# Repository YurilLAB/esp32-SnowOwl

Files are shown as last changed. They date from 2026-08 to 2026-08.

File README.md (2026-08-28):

<div align="center">

# 🦉 ESP32-SnowOwl

**A multi-purpose wireless _offensive &amp; defensive_ security multitool.**

Three processors — **ESP32-S3 + ESP32-C5 (5 GHz Wi‑Fi) + ARM Linux** — driving a wall of radios and readers: dual‑band Wi‑Fi, BLE, 2.4 GHz, Sub‑GHz, **LoRa**, IR, **NFC**, **125 kHz RFID**, **iButton** &amp; GPS, in one stackable handheld.








</div>

> ⚠️ **Authorized use only.** SnowOwl is built for security research, education, CTFs, and testing on systems you own or are explicitly authorized to assess. You are solely responsible for complying with all applicable laws and regulations.

---

## 📖 About

**ESP32-SnowOwl** is a hardware evolution of [CiferTech's **ESP32‑DIV**](https://github.com/cifertech/ESP32-DIV) — the open-source ESP32‑S3 wireless multitool. SnowOwl keeps the entire ESP32‑DIV toolset and then piles on the compute, radios and readers the stock board doesn't have.

**Three processors, each doing what it's best at:**

- 🦅 **ESP32‑S3 — the controller.** The base ESP32‑DIV brain: the on‑device UI, 2.4 GHz Wi‑Fi &amp; BLE, and orchestration of every radio.
- 📡 **ESP32‑C5 — the 5 GHz reach.** A dual‑band **Wi‑Fi 6 (2.4 + 5 GHz)** co‑processor that adds the entire **5 GHz** band the S3 can't touch, on its own antenna and its own regulated rail.
- 🐧 **RV1106 ARM Linux — the analyst.** A real Linux computer (Luckfox Core1106) for capture, monitoring, scripting and heavy on‑device tooling — self‑powered from **its own USB‑C**.

Offense on the talons, analysis in the eyes. Silent, patient, built for the dark — the snow owl fits.

---

## 🦉 What SnowOwl adds over ESP32‑DIV

| Addition | Part | What it brings |
|---|---|---|
| 📡 **5 GHz Wi‑Fi co‑processor** | ESP32‑C5‑WROOM‑1U | Dual‑band **Wi‑Fi 6 (2.4 + 5 GHz)** — the 5 GHz band the ESP32‑S3 can't reach. Own U.FL antenna, own AP7361C LDO rail, UART‑linked to the S3. |
| 🐧 **ARM Linux co‑processor** | Luckfox RV1106 (Core1106) | A genuine Linux computer on the shield for capture, monitoring and heavy tooling. Self‑powered from **its own USB‑C**. |
| 🧲 **NFC** (13.56 MHz) | PN532 | Read / emulate / relay over a **dedicated I²C bus** owned by the S3 — independent of the radios. |
| 📇 **125 kHz LF RFID** | HTRC110 + coil | Low‑frequency prox‑card read &amp; emulation (EM4100‑class) — a band the stock board lacks. |
| 🔑 **iButton / 1‑Wire** | 1‑Wire header | Dallas iButton + 1‑Wire contact interface. |
| 📻 **LoRa / long‑range Sub‑GHz** | SX1262 (+ Johanson match) | Long‑range LoRa &amp; FSK on Sub‑GHz, alongside the OOK/ASK radios. |
| 📻 **High‑performance Sub‑GHz** | CC1200 | A higher‑performance Sub‑GHz transceiver in addition to the classic CC1101. |
| 💾 **External flash** | W25Q128 (16 MB) | Non‑volatile storage for captures, logs and dumps. |
| 🧱 **4‑layer, power‑hardened PCB** | — | Dedicated **GND** and **3V3** planes, per‑rail decoupling and bulk caps for clean RF and stable multi‑radio operation. |

---

## 🎯 Features

SnowOwl runs the full **ESP32‑DIV** firmware feature set on the ESP32‑S3, extended with the SnowOwl radios and readers. Capabilities by band:

### 📡 Wi‑Fi — 2.4 GHz (ESP32‑S3) **+ 5 GHz (ESP32‑C5)** · **5 GHz is NEW**
| Capability | Notes |
|---|---|
| Dual‑band recon &amp; scanning | AP / station discovery across **2.4 *and* 5 GHz**, channels, RSSI |
| Deauth / attack testing | Targeted &amp; broadcast frame testing, now on 5 GHz networks too |
| Beacon / probe flooding | SSID beacon spam, probe generation |
| Packet monitor / capture | Sniffing, with hand‑off to the ARM side for storage &amp; analysis |
| Evil‑portal / captive testing | Rogue‑AP and captive‑portal workflows |

### 🔵 Bluetooth / BLE
| Capability | Notes |
|---|---|
| BLE scan &amp; recon | Device discovery, service enumeration |
| Advertising / spam | BLE advertisement flooding &amp; spoofing |
| Proximity‑pairing tests | Device‑spam nuisance testing |

### 📶 2.4 GHz / nRF24 (3× nRF24L01+)
| Capability | Notes |
|---|---|
| Channel scanner / analyzer | 2.4 GHz spectrum sweep across three radios |
| Multi‑channel jamming (test) | Wide/targeted 2.4 GHz interference testing |

### 📻 Sub‑GHz — CC1101 · CC1200 · **SX1262 LoRa**
| Capability | Notes |
|---|---|
| Scan &amp; frequency analysis | RSSI sweep, signal hunting |
| Capture / replay | Record &amp; re‑transmit OOK/ASK signals |
| **LoRa / long‑range** | SX1262 for LoRa &amp; long‑range FSK |
| Jamming (test) | Sub‑GHz interference testing |

### 📺 Infrared (TSOP1838 RX + IR TX)
| Capability | Notes |
|---|---|
| Receive / decode | Capture IR remotes |
| Send / replay | Transmit stored or brute‑forced codes |

### 🧲 NFC / RFID — 13.56 MHz (PN532)
| Capability | Notes |
|---|---|
| Read / dump | MIFARE‑class tags &amp; UIDs |
| Emulate / relay | Card emulation and relay over the dedicated I²C bus |

### 📇 LF RFID — 125 kHz (HTRC110) &amp; 🔑 iButton · **NEW**
| Capability | Notes |
|---|---|
| 125 kHz read / emulate | EM4100‑class prox cards |
| iButton / 1‑Wire | Dallas contact keys |

### 🛰️ GPS (NEO‑M9N)
| Capability | Notes |
|---|---|
| Location &amp; time | Fix, NMEA, wardriving support |

### 🐧 ARM Linux co‑processor (RV1106) · **NEW**
| Capability | Notes |
|---|---|
| On‑device capture &amp; storage | Long‑running packet/loot capture without a laptop, to the 16 MB flash / SD |
| Monitoring / blue‑team | Run standard Linux security &amp; monitoring tooling on‑device |
| Scripting &amp; automation | Python/shell orchestration of the S3 &amp; C5 radios |

### 🧰 Device &amp; System
| Capability | Notes |
|---|---|
| Display UI | On‑device menu on the ESP32‑DIV TFT |
| Storage | microSD + **16 MB external flash** |
| Settings | Per‑module configuration |

> The exact per‑tool menu is inherited from the ESP32‑DIV firmware — see the [ESP32‑DIV wiki](https://github.com/cifertech/ESP32-DIV/wiki) for the full tool list.

---

## 🔧 Hardware Overview

### 🧠 Compute
- **ESP32‑S3** — application processor, 2.4 GHz Wi‑Fi &amp; BLE, UI (on the main board)
- **ESP32‑C5‑WROOM‑1U** — dual‑band **2.4 / 5 GHz Wi‑Fi 6** co‑processor (U.FL antenna, AP7361C LDO rail, UART link)
- **Luckfox RV1106 (Core1106)** — ARM Linux SoM, self‑powered via its **own USB‑C**

### 📡 Radios
- **3× nRF24L01+** — 2.4 GHz
- **CC1101** + **CC1200** — Sub‑GHz transceivers
- **SX1262** (+ Johanson integrated match) — LoRa / long‑range Sub‑GHz
- **7× SMA** antenna ports + U.FL

### 🧲 Readers &amp; sensors
- **PN532** — 13.56 MHz NFC (dedicated I²C bus, 27.12 MHz)
- **HTRC110** + coil — 125 kHz LF RFID
- **iButton / 1‑Wire** contact interface
- **TSOP1838** IR receiver + IR transmit
- **NEO‑M9N** — GPS

### 🔌 Power, storage &amp; protection
- **W25Q128** — 16 MB SPI flash
- microSD
- **AP7361C‑3.3** LDO (C5 rail), dedicated USB‑C for the ARM SoM
- **USBLC6‑2SC6** USB ESD protection, **SN74LVC2G34** level buffer
- Power hardening: bulk + per‑rail decoupling capacitors

Mates to the main board through the existing 20‑pin stack header; pogo/standoff holes are kept clear for a flat stack.

---

## 🧱 PCB / Manufacturing

- Designed in **KiCad 10**.
- **4‑layer stackup** — `F.Cu (signal) · In1 (GND plane) · In2 (3V3 plane) · B.Cu (signal)` for clean RF return paths and a quiet supply.
- Power‑planned per the datasheets of each part (per‑rail decoupling + bulk); RF nets use integrated matching where the transceiver vendors provide it.
- Intended for standard 4‑layer fabrication (e.g. JLCPCB); the 4‑layer option adds only a few dollars per unit over 2‑layer.

> **Status:** hardware design in active development. Placement and power are complete; signal routing is being finished. Renders and design notes live in [`/hardware`](hardware).

---

## ⚠️ Legal &amp; Responsible Use

SnowOwl is an **offensive *and* defensive** research platform. It is intended **only** for:

- testing systems you **own** or are **explicitly authorized** to assess,
- security education, CTFs, and lab research,
- defensive monitoring and blue‑team work.

Do **not** use it to access, disrupt, or interfere with networks, devices, cards, or systems you do not own or lack permission to test. Radio transmission is regulated — respect your local RF laws and licensed bands. **You** are responsible for how you use this tool.

---

## 📜 License

Released under the **MIT License** — see [`LICENSE`](LICENSE).

SnowOwl is a derivative of **ESP32‑DIV** (© CiferTech, MIT). The original work's terms are honored and its authors are credited below.

---

## 🙌 Credits

- **[CiferTech](https://github.com/cifertech)** — the original [ESP32‑DIV](https://github.com/cifertech/ESP32-DIV) platform and firmware that SnowOwl builds on. 🙏
- **YurilLAB** — SnowOwl hardware: the 5 GHz Wi‑Fi + ARM‑Linux compute, the NFC / 125 kHz RFID / iButton / LoRa additions, power hardening, and the 4‑layer redesign.

---

## 💬 Contributing &amp; Support

Issues, ideas, and pull requests are welcome. If SnowOwl is useful to you, a ⭐ helps.

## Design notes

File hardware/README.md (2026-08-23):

# 🦉 ESP32-SnowOwl — Hardware

KiCad design for the SnowOwl 2-board stack (main board + shield).

## PCB source → [`../PCB/`](../PCB)

All CAD lives under [`../PCB/`](../PCB), with old and new kept separate:

- **[`PCB/v2-compact/`](../PCB/v2-compact)** — the **active** ground-up remake: a compact,
  deliberately floorplanned **2-board stack** (`main-board/` + `shield/`). Start with
  [`PCB/v2-compact/PLACEMENT.md`](../PCB/v2-compact/PLACEMENT.md) for the zone map and the
  bus/routing strategy.
- **[`PCB/v1-original/`](../PCB/v1-original)** — the original board, archived (renders only).

## Renders (v1)

| Front | Back |
|---|---|
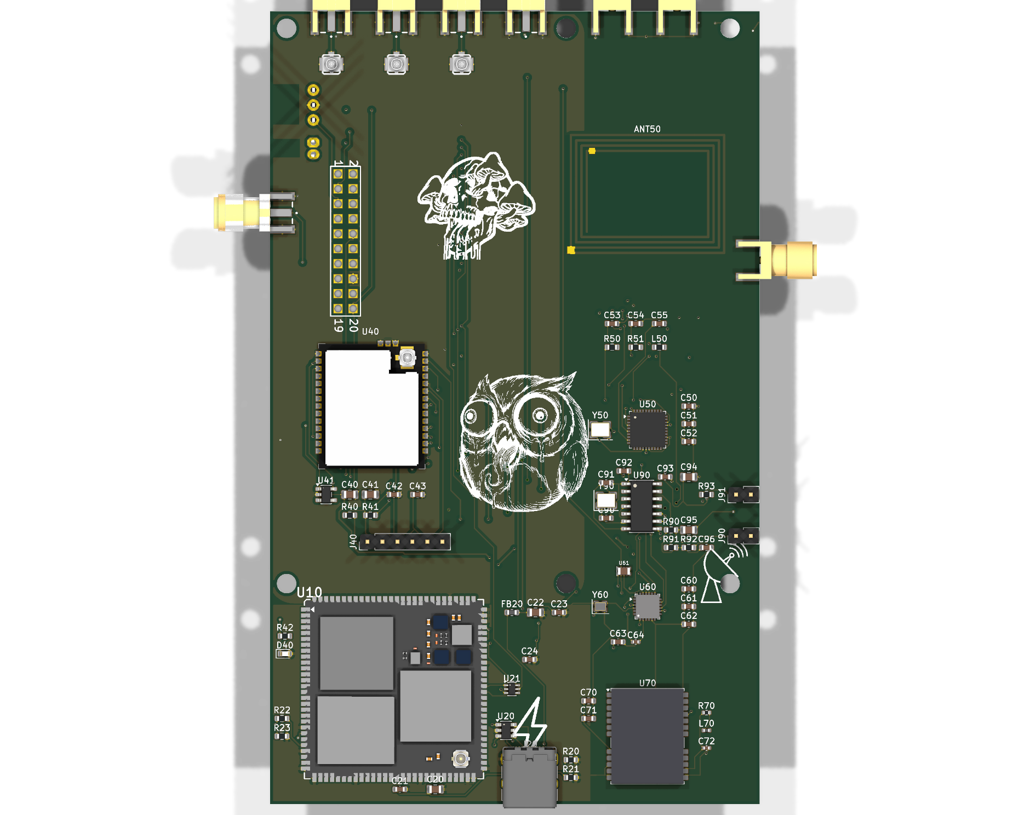
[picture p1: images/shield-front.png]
front
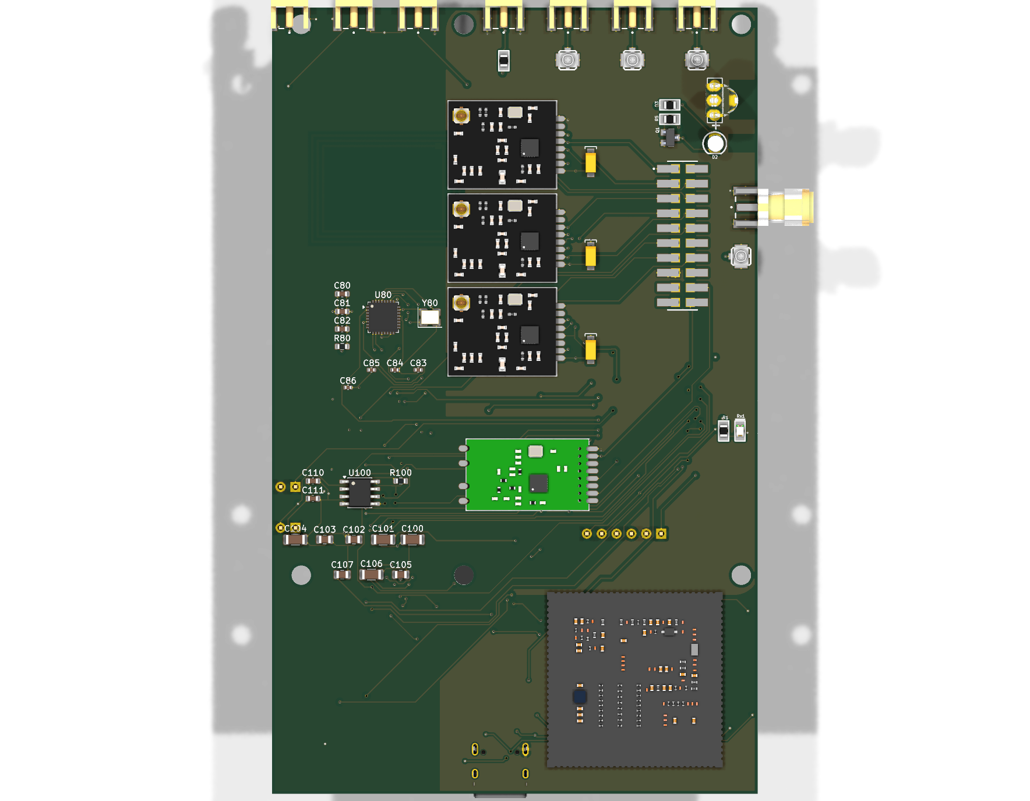
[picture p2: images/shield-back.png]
back
|  |  |

## Shield highlights

- **ESP32-C5-WROOM-1U** — dual-band **2.4 / 5 GHz Wi-Fi 6** co-processor (adds the 5 GHz band the S3 lacks); own U.FL antenna + **AP7361C-3.3** LDO rail, UART-linked to the S3.
- **Luckfox RV1106 (Core1106)** ARM Linux SoM — self-powered from its **own USB-C** (isolated from the main board's supply).
- **PN532 NFC** (13.56 MHz, 27.12 MHz clock) on a dedicated I²C bus owned by the ESP32-S3.
- **HTRC110 125 kHz LF RFID** front-end + coil connector.
- **iButton / 1-Wire** contact interface.
- **SX1262 LoRa** (+ Johanson integrated match) and **CC1200** high-performance Sub-GHz, alongside the classic CC1101.
- **3× nRF24L01+** (2.4 GHz) and **NEO-M9N** GPS.
- **W25Q128** 16 MB external flash for captures/logs.
- Power hardening: bulk + per-rail decoupling capacitors; **USBLC6** USB ESD protection.
- Mates to the main board via the existing 20-pin stack header; pogo/standoff holes kept clear for a flat stack.

## Stackup (4-layer)

| Layer | Role |
|---|---|
| `F.Cu`  | Signal |
| `In1.Cu` | **GND plane** |
| `In2.Cu` | **3V3 plane** |
| `B.Cu`  | Signal |

Dedicated planes give every radio a solid return path and a quiet supply — the single biggest win for multi-radio RF behaviour. Standard 4-layer fabrication (e.g. JLCPCB) adds only a few dollars per unit over 2-layer.

## Status

**Redesign in progress — v2 (2-board stack).** The board is being remade from scratch to
fix v1's spread-out placement (which forced long cross-board traces). v2 keeps every
radio/reader but floorplans each subsystem deliberately so routing stays local.

Current v2 state (in [`../PCB/v2-compact/`](../PCB/v2-compact)): floorplan **skeleton** —
both KiCad projects open with the compact `60 × 85 mm` outline, the 4-layer stackup, the
shared 20-pin `J1` stack datum, mounting holes, and labelled placement zones. Symbols,
footprints and routing are the next passes. The RF nets (Sub-GHz, NFC coil, GPS) are still
reserved for short, matched hand-routing.

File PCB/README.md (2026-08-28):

# 🦉 SnowOwl — PCB

**Clean slate.** All previous CAD — boards, schematics, footprints, floorplan and renders — has
been wiped. The hardware direction is changing and the design is being started over from scratch.

```
PCB/
└── RESEARCH.md    ← component & schematic reference carried over from the old attempt
```

## RESEARCH.md

The only thing kept: the electrical research worth not repeating.

- **System architecture** — which processor owns what, and the SPI-spine approach.
- **Component inventory** — every radio/reader, and which ones are self-contained modules vs.
  chip-down parts that need a crystal and an RF front-end.
- **Power** — the single-USB-C / battery topology, plus **datasheet pinout corrections** for the
  charger, regulators and fuel gauge (the old symbols had invented pinouts).
- **RF front-end topologies** — matching + filter chains for the chip-down radios, with the
  caveat that every L/C value still needs VNA tuning.
- **Schematic gotchas** — including the net-merge bug that silently shorted whole nets twice.

It deliberately assumes **no particular board size, layout or form factor**, so none of it
constrains the new design.

> Fabrication outputs (`gerbers-out/`, zips) are git-ignored.

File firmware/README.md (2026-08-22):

# 🦉 ESP32-SnowOwl — Firmware

SnowOwl is a **three-processor** device, so there are three firmware sides.

## 🦅 ESP32-S3 (controller + main radios)

- **Base:** the [ESP32-DIV firmware](https://github.com/cifertech/ESP32-DIV) (Arduino / PlatformIO) — the full wireless toolset runs unchanged.
- **SnowOwl add-ons:**
  - **PN532 NFC** over the dedicated I²C bus.
  - **HTRC110 125 kHz LF RFID** read / emulate.
  - **iButton / 1-Wire** contact interface.
  - **SX1262 LoRa** + **CC1200** Sub-GHz drivers.

Flashing follows the ESP32-DIV instructions (USB-C, `esptool` / PlatformIO, or the browser flasher).

## 📡 ESP32-C5 (5 GHz Wi-Fi co-processor)

- Runs its own ESP-IDF firmware and is **UART-linked to the S3**, which requests 5 GHz scans/attacks and receives results to draw on the TFT.
- Adds the dual-band **2.4 / 5 GHz Wi-Fi 6** capability the S3 (2.4 GHz only) can't provide.
- Flashed over its own USB / `C5_PROG_UART` header.

## 🐧 RV1106 (ARM Linux co-processor)

- Runs a standard Linux userland (Luckfox Buildroot / Ubuntu image) from its own storage, powered by its own USB-C.
- Talks to the ESP32-S3 over the inter-processor link for capture, monitoring and orchestration.
- Intended home for heavier tooling the ESP32 can't run — packet capture, analysis, scripting, blue-team monitoring.

## Status

Firmware integration is in progress. Until the SnowOwl builds are published here, use the upstream [ESP32-DIV firmware + wiki](https://github.com/cifertech/ESP32-DIV/wiki) as the reference for the base toolset.

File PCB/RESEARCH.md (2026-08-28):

# SnowOwl / ESP32-BlackRaven — component & schematic research

Electrical reference carried over from the earlier attempt. **All CAD (boards, schematics,
floorplan, renders) was wiped and is being redone** — the project direction is changing. What
survives here is only the research worth not repeating: what the parts are, how they connect,
and the datasheet findings.

Nothing here assumes a particular board size, layout or form factor.

---

## 1. System architecture

| Controller | Owns | Link |
|---|---|---|
| **ESP32-S3** | UI: TFT, LEDs, nav buttons, microSD; and NFC, iButton, IR | the brain |
| **ESP32-C5** | the SPI radio spine — CC1101, CC1200, SX1262, 3× nRF24, W25Q128 flash; plus 5GHz Wi-Fi and the 125kHz HTRC110 | UART pair + data-ready line to the S3 |
| **RV1106** | ARM Linux SoM, own microSD | UART to the S3 |

**Key decision:** the C5 sits among the radios and masters one short SPI spine; every radio taps
it with a short stub. The S3 never reaches the radios directly — it commands the C5 over UART.
An **MCP23S17** expander generates the per-radio chip-selects so the C5 doesn't burn GPIO.

## 2. Component inventory

| Function | Part | Notes |
|---|---|---|
| Main MCU | ESP32-S3 | UI + brain |
| Radio co-processor | ESP32-C5-WROOM-1U | 5GHz Wi-Fi; **module — own antenna** |
| CS expander | MCP23S17 | SPI → chip-selects |
| Sub-GHz | **CC1101** | **plug-in module** (2×4 header) |
| Sub-GHz | **CC1200** | chip-down, needs 40MHz xtal + RF front-end |
| LoRa | **SX1262** | chip-down, needs 32MHz xtal + RF front-end |
| 2.4GHz | 3× nRF24L01+ | **modules — own antennas** |
| NFC | PN532 | 13.56MHz |
| LF RFID | HTRC110 | 125kHz, **5V part**, open-drain DOUT pulled to 3V3 — level-shift care needed vs the 3.3V C5 |
| GPS | u-blox NEO-M9N | chip-down, needs antenna bias-tee |
| IR | receiver + TX LED + transistor | |
| iButton | 1-Wire | |
| Flash | W25Q128 | 16MB, on the SPI spine |
| Linux | RV1106 "Core1106" SoM | + own microSD |
| Display | TFT on FPC header | |

### Radios that need on-board RF vs. those that don't
- **Need a front-end (chip-down):** CC1200, SX1262, GPS NEO-M9N.
- **Self-contained (own crystal + antenna):** nRF24 ×3, CC1101, ESP32-C5-WROOM-1U.

> **CC1101 is a module, not a chip** — a 2×4 pin header: GND, +3V3, SPI SCK/MOSI/MISO, CSN,
> GDO0, GDO2. It needs no crystal and no RF path, only decoupling. (This confused us once.)

## 3. Power

**One USB-C for the whole device.** Everything runs off the battery; USB only charges.

```
USB-C → VBUS → BQ25896 charger ─┬→ VBAT  (LiPo ~2500mAh, ≈1–2h active runtime)
                                 └→ VSYS ─┬→ TPS63020 buck-boost → +3V3
                                          └→ TPS61230A boost     → +5V
```
Plus **MAX17048** fuel gauge and **DW01A + FS8205A** cell protection, both readable over I²C.
The RV1106 has microSD but no USB port of its own — reached over UART.

### ⚠ Datasheet pinout corrections (researched, never applied — the old symbols were WRONG)

- **BQ25896** (QFN-24): has **no D+/D− pins** — it uses **PSEL (2)** and **PG (3)**.
  VBUS=1, STAT=4, SCL=5, SDA=6, INT=7, OTG=8, CE=9, ILIM=10, TS=11, QON=12, BAT=13/14,
  SYS=15/16, PGND=17/18+EP, SW=19/20, BTST=21, REGN=22, PMID=23, NC=24.
  App values: inductor **1µH**, R_ILIM ≈ **180Ω** for 2A, TS divider **10k/10k**,
  charge current set over I²C (2048mA).
- **TPS63020**: **14-pin VSON**, not 10-pin. Inductor **1.5µH**, FB **0.5V**,
  3.3V divider **R1=1M / R2=180k**.
- **TPS61230A**: **7-pin 2×2 VQFN** — CBST=1, EN=2, FB=3, VIN=4, SW=5, GND=6, VOUT=7.
  Inductor **1µH**, FB **1.2V**, 5V divider **R1=316k / R2=100k**.
- **MAX17048**: separate **CELL (2)** and **VDD (3)** pins.
- USB-C **5.1k CC resistors** — confirmed correct.

## 4. RF front-end designs

**All L/C values below are FIRST-PASS starting points — they must be tuned with a VNA** against
each chip's reference design and the final board's 50Ω trace impedance.

| Radio | Chain |
|---|---|
| **CC1200** | PA + LNA lumped match → 2-section harmonic LPF → antenna |
| **SX1262** | DC-DC coil (≈15µH) + PA-regulator cap; RFO/RFI match → 2-section LPF → antenna |
| **GPS** | active-antenna bias-tee: series DC-block cap + DC feed inductor/ferrite from the RF supply |

Edge-mount SMA convention: **pin 1 = signal, pin 2 = GND shield**, barrel pointing off the edge.

⚠ **The CC1200 RF pinout (PA / TRXSW / LNA_P / LNA_N / LPF0 / LPF1) was never datasheet-verified.**
Confirm it before designing that match again.

## 5. Schematic gotchas worth remembering

- **eeschema has no Python API.** Schematics have to be hand-authored as S-expressions (or drawn
  by hand); `kicad-cli sch export netlist` is what drives everything downstream.
- **Auto-generated stub collisions silently merge nets.** When a generator drops a short wire stub
  + net label at each pin, packing parts into a 2-D grid can land a shunt-to-GND stub exactly on a
  signal stub — fusing whole nets with no error. It bit us twice: once shorting GND to a decoupling
  net, once merging *every* antenna net into GND. **Lay each network out as a single well-spaced
  row with distinct X positions**, and always re-verify net node counts after generating — a rail
  with a suspiciously large node count means a merge happened.
- **Verify a symbol's pin count against the datasheet before trusting it** — several power ICs
  above were placeholder symbols with invented pinouts, and it wasn't caught until much later.

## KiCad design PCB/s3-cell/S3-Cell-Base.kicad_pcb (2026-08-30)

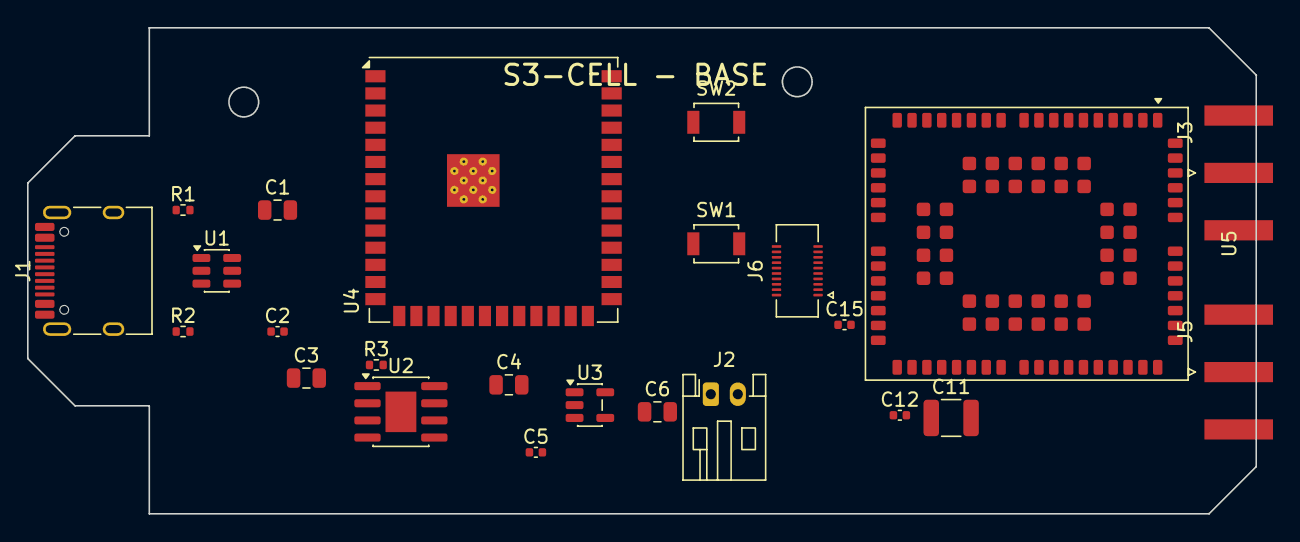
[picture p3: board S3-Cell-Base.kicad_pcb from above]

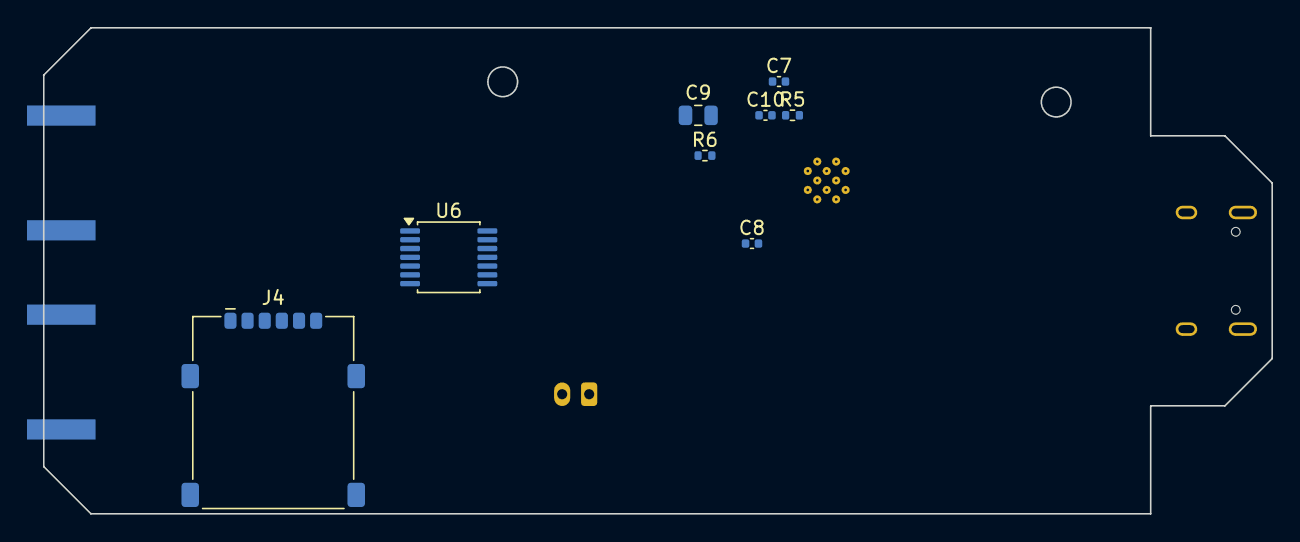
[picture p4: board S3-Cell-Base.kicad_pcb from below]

Board: 4 copper layers, 91.0 x 36.0 mm, 32 parts (8 on the bottom side), 14 nets, no tracks yet.

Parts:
C1, C3, C4, C6: 10uF; C_0805_2012Metric
C2, C7, C8, C12, C15: 100nF; C_0402_1005Metric
C5, C10: 1uF; C_0402_1005Metric
C9: 22uF; C_0805_2012Metric
C11: 100uF; C_1210_3225Metric
J1: USB-C; USB_C_Receptacle_HRO_TYPE-C-31-M-12
J2: BATT; JST_PH_S2B-PH-K_1x02_P2.00mm_Horizontal
J3: SMA; SMA_Amphenol_132289_EdgeMount
J4: nanoSIM; nanoSIM_GCT_SIM8060-6-0-14-00
J5: SMA_GNSS; SMA_Amphenol_132289_EdgeMount
J6: DF40C-2x10 (stack); Hirose_DF40C(2.0)-20DS-0.4V_2x10_P0.4mm
R1, R2: 5.1k; R_0402_1005Metric
R3: 1.2k; R_0402_1005Metric
R5, R6: 10k; R_0402_1005Metric
SW1: BOOT; SW_SPST_B3U-1000P
SW2: RST; SW_SPST_B3U-1000P
U1: USBLC6-2SC6; SOT-23-6
U2: TP4056; SOIC-8-1EP_3.9x4.9mm_P1.27mm_EP2.29x3mm
U3: AP2112-3.3; SOT-23-5
U4: ESP32-S3-WROOM-1U
U5: BG95-M3; Quectel_BG95
U6: TXB0104; TSSOP-14_4.4x5mm_P0.65mm

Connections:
+3V3: C6.1, C7.1, C8.1, C9.1, R5.2, R6.2, U3.5, U4.2
ANT_GNSS: J5.1, U5.49
ANT_MAIN: J3.1, U5.60
EN: C10.1, R5.1, SW2.1, U4.3
GND: C1.2, C2.2, C3.2, C4.2, C5.2, C6.2, C7.2, C8.2, C9.2, C10.2, C11.2, C12.2, C15.2, J1.A1, J1.A8, J1.A12, J1.B1, J1.B8, J1.B12, J1.SH, J2.2, J3.2, J4.SH, J5.2, R1.2, R2.2, R3.2, SW1.2, SW2.2, U1.2, U2.1, U2.3, U2.9, U3.2, U4.1, U4.40, U4.41, U5.47
IO0: R6.1, SW1.1, U4.27
PROG: R3.1, U2.2
USB_CC1: J1.A5, R1.1
USB_CC2: J1.B5, R2.1
USB_DM: J1.A7, J1.B7, U1.3, U1.4, U4.13
USB_DP: J1.A6, J1.B6, U1.1, U1.6, U4.14
VBAT: C4.1, C5.1, C11.1, C12.1, J2.1, U2.5, U2.6, U3.1, U3.3, U5.32, U5.33, U5.52, U5.53
VBUS: C1.1, C2.1, C3.1, J1.A4, J1.A9, J1.B4, J1.B9, U1.5, U2.4
VDD_EXT: C15.1, U5.29

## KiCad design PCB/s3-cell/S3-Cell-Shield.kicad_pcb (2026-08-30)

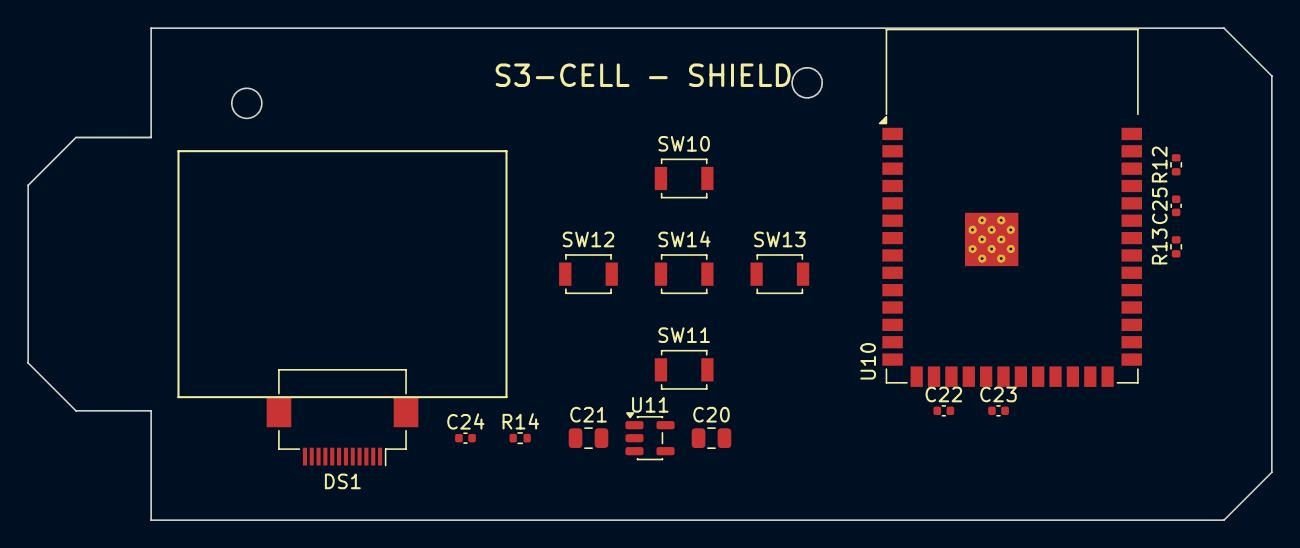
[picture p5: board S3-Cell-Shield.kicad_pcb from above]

Board: 4 copper layers, 91.0 x 36.0 mm, 18 parts (1 on the bottom side), 3 nets, no tracks yet.

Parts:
C20, C21: 10uF; C_0805_2012Metric
C22, C23, C24, C25: 100nF; C_0402_1005Metric
DS1: TFT 1.14" ST7789; Hirose_FH12-12S-0.5SH_1x12-1MP_P0.50mm_Horizontal
J6: DF40C-2x10 (stack); Hirose_DF40C-20DP-0.4V_2x10-1MP_P0.4mm
R12, R13: 10k; R_0402_1005Metric
R14: BL 10R; R_0402_1005Metric
SW10: UP; SW_SPST_B3U-1000P
SW11: DOWN; SW_SPST_B3U-1000P
SW12: LEFT; SW_SPST_B3U-1000P
SW13: RIGHT; SW_SPST_B3U-1000P
SW14: SEL; SW_SPST_B3U-1000P
U10: ESP32-C5-WROOM-1; ESP32-S3-WROOM-1
U11: AP2112-3.3; SOT-23-5

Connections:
+3V3S: C21.1, C22.1, C23.1, R12.1, R13.1, R14.1
C5_EN: C25.1, R12.2
GND: C20.2, C21.2, C22.2, C23.2, C25.2, SW10.2, SW11.2, SW12.2, SW13.2, SW14.2

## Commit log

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2026-08-23 PCB: start v2 remake — compact 2-board stack with deliberate floorplan
    Set up a PCB/ tree that keeps the old and new designs separate, and lay the
    foundation for the from-scratch redesign of BOTH boards as a stackable 2-board
    set, floorplanned so subsystems route locally instead of trailing traces across
    the whole board.
    PCB/
    v1-original/ archived original board (renders only — v1 had no CAD source)
    v2-compact/ new design (active)
    main-board/ ESP32-S3 brain + UI + power + microSD + stack header
    shield/ C5, RV1106, CC1101/CC1200/SX1262, 3x nRF24, PN532, HTRC110,
    GPS, IR, iButton, W25Q128 — every v1 radio/reader kept
    Each board is an openable KiC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
    [SnowOwl-Main.kicad_pcb, SnowOwl-Main.kicad_sch, SnowOwl-Shield.kicad_pcb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]
2026-08-23 PCB: rework main board to phone-style layout; J1 -> horizontal strip
    Main board (per feedback) is now a phone-style split — front is pure UI, back
    carries the electronics:
    - FRONT: status LEDs at the very top (above the display), TFT rotated to
    LANDSCAPE (sideways), nav buttons below it and moved down. Same feel as the
    ESP32-DIV, sideways screen.
    - BACK: ESP32-S3 behind the display, microSD beside it, power + USB-C at the
    bottom-centre edge like a phone.
    To keep the centre column free for the landscape display and the bottom-centre
    USB-C, J1 is reoriented from a vertical 2x10 to a HORIZONTAL 10x2 strip in the
    lower-centre. J1 is the shared mating datum, so the shield's J1 moves to m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
    [SnowOwl-Main.kicad_pcb, SnowOwl-Main.kicad_sch, SnowOwl-Shield.kicad_pcb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]
2026-08-23 PCB v2: grow to 70x100mm and adopt the C5-owns-radios architecture
    Refit the outline to 70x100 after a footprint fit-check: 60x85 could not hold
    the RV1106 SoM plus the C5 and nRF24 modules without cramming, which is what
    forces congested traces.
    - ESP32-C5 now masters the shield SPI spine; every SPI radio taps off it, so
    the whole radio fan-out stays on the shield next to the C5. The S3 commands
    the C5 over one UART on J1 and no SPI radio line crosses the stack header.
    - Reflow both boards' zones for short-trace placement, sized to the real part
    footprints; keep the shared J1 datum (53.57, 106.0) so the boards still stack.
    - Lock the J1 pinout: power + I2C(PN532) + S3<->C5 UART + S3<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
    [SnowOwl-Main.kicad_pcb, SnowOwl-Shield.kicad_pcb, SnowOwl-Shield.kicad_sch]
2026-08-23 Schematics: fix hierarchy load, add verified generator, capture flash sheet
    The v2 schematic roots were missing the per-sheet (instances) block, so the
    projects would not load in KiCad (kicad-cli failed on both). Regenerate both
    roots in a verified format (netlist export now succeeds on both boards).
    Populate the first sub-sheet (12_Flash) as the proven pattern: real W25Q128
    symbol, decoupling, wired to the SPI spine and power by global labels. Verified
    by netlist (U12 pins map to FLASH_CS / SPI_SCK / SPI_MOSI / SPI_MISO / +3V3 / GND).
    Remaining sub-sheets to follow the same pattern.
    [SnowOwl-Main.kicad_sch, SnowOwl-Shield.kicad_sch, flash.kicad_sch]
2026-08-23 Schematics: custom symbols + footprint lib + backbone/nRF24/iButton sheets
    - Add SnowOwl.kicad_sym (nRF24 + CC1101 module symbols; MISO tri-state for the
    shared SPI bus) and SnowOwl.pretty with the 2x10 stack-header footprint,
    registered via project sym-lib-table / fp-lib-table on both boards.
    - Capture sheets, each netlist- and ERC-checked:
    - J1 stack header (both boards) wired to the locked pinout (the interconnect
    backbone: power + I2C + S3<->C5 UART + S3<->RV1106 UART + IR + 1-Wire)
    - nRF24 x3 on the shared SPI spine (per-radio CE/CSN/IRQ) with decoupling
    - iButton 1-Wire with pull-up
    - Engine: snap all placements to the 1.27mm grid (clears 103 off-grid warnings);
    globall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
    [flash.kicad_sch, ibutton.kicad_sch, nrf24.kicad_sch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]
2026-08-24 Schematics: capture PN532, GPS, IR, and both power sheets
    - 07_NFC_PN532: I2C mode (I0/I1 set), 27.12MHz crystal, VMID cap, internal
    DVDD/SVDD regulator outputs correctly decoupled (not tied to 3V3), pull-ups;
    antenna pins flagged for the RF matching pass.
    - 10_GPS: NEO-M9N UART to the C5, power + decoupling; bias-tee/antenna flagged.
    - 11_IR: TSOP receiver + IR-LED transmitter (NPN driver).
    - 02_Power (shield): local AP7361C LDO for the C5 rail + bulk caps + PWR_FLAGs.
    - 01_Power_USB (main): USB-C, CC resistors, USBLC6 ESD, AP7361C 3V3 LDO.
    All netlist-verified. Remaining ERC items are expected WIP (no-connects on unused
    IC pins + power flags), to be cleaned once the MCU sheets tie in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
    [gps.kicad_sch, ibutton.kicad_sch, ir.kicad_sch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]
2026-08-24 Schematics: ESP32-C5 hub sheet with MCP23S17 CS/IO expander
    The C5's ~22 GPIO cannot drive all the radio control lines directly, so per the
    plan the C5 sheet adds an MCP23S17 SPI I/O expander on the shield:
    - C5 masters the SPI spine (SCK/MOSI/MISO), talks to the S3 over UART0 (also on
    the J40 prog header), and drives the timing-critical lines directly (the three
    nRF24 CE lines, SX1262 BUSY).
    - MCP23S17 (U42) generates the seven chip-selects + SX1262 reset on its GPA
    outputs and reads the radio IRQs on its GPB inputs, all local to the shield.
    - EN/boot RC + pull-ups, decoupling, U.FL on C5_ANT.
    Netlist-verified: SPI_SCK/MISO reach every slave + master + expander; FLASH_CS
    and the NRFn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
    [esp32c5.kicad_sch, gps.kicad_sch, ibutton.kicad_sch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]
2026-08-24 Schematics: main board ESP32-S3, microSD, and display/UI sheets
    - 02_ESP32-S3: the brain. Shared SPI (LCD_SCK/MOSI + SD_MISO) for TFT and
    microSD, USB data to the USB-C through the ESD, and the full J1 interface to
    the shield (C5 UART + DRDY, I2C to PN532, RV1106 UART, IR, 1-Wire). EN/boot RC
    + decoupling.
    - 04_microSD: SPI-mode card with CS pull-up + decoupling.
    - 03_Display_UI: SPI TFT header, five nav buttons to GND, two status LEDs.
    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
    [display_ui.kicad_sch, esp32c5.kicad_sch, esp32s3.kicad_sch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]
2026-08-24 Schematics: sub-GHz trio sheet (CC1200 + SX1262 + CC1101) + fixes
    - 05_SubGHz (A3): CC1200 and SX1262 (bare QFN) with SPI, control, power,
    crystals and decoupling wired; CC1101 as an 8-pin module. Chip-selects come
    from the MCP23S17 (CC1200_CS, SX1262_NSS, CC1101_CSN), SX1262 BUSY direct on
    the C5. RF front-ends (PA/LNA/RFO/RFI -> match -> SMA) flagged for the RF pass.
    Verified: SPI_SCK now reaches all nine SPI devices.
    - Fix the Espressif symbol-lib-table path to Windows form (was Git-Bash /d/...).
    - Add A3 page support to the generator.
    [display_ui.kicad_sch, esp32c5.kicad_sch, esp32s3.kicad_sch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]
2026-08-24 Schematics: HTRC110 and RV1106 sheets — full sheet set complete
    - 08_LF_RFID_HTRC110: 5V HITAG reader, 3-wire (SCLK/DIN/DOUT) to the C5, DOUT
    open-drain pulled to 3.3V, 4MHz crystal, decoupling. LF coil tank flagged;
    pins 8-14 flagged to verify against the datasheet.
    - 04_RV1106_Linux (A3): Core1106 SoM self-powered from its own USB-C (CC
    resistors) with its own microSD; UART to the S3 over J1 (RV_TX/RX/CTRL).
    Symbol is functional with placeholder pin numbers, flagged to verify against
    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
    [display_ui.kicad_sch, esp32c5.kicad_sch, esp32s3.kicad_sch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]
2026-08-24 Schematics: cleanup - HTRC110 footprint (SOIC-14), reset pull-ups (CC1200/GPS), RV1106 power flags
    [display_ui.kicad_sch, esp32c5.kicad_sch, esp32s3.kicad_sch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]
2026-08-24 PCB: import schematic netlists onto both boards (parts placed + nets assigned)
    Load every footprint from the schematic into the floorplan-skeleton boards,
    place each in its subsystem's zone (grid-spread, back-side sheets flipped), and
    assign all nets. Shield: 79 parts, 419 pad-nets, 153 nets. Main: 29 parts,
    150 pad-nets, 57 nets. Register the Espressif footprint library; add a
    placeholder Core1106 SoM footprint; assign the C5 (Espressif), NEO-M9N (ublox_NEO)
    and CC1101 (2x4 header) module footprints.
    This is the initial import: every part is on its board with the full ratsnest,
    ready for placement refinement and routing.
    [SnowOwl-Main.kicad_pcb, SnowOwl-Shield.kicad_pcb, display_ui.kicad_sch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]
2026-08-24 PCB: intentional floorplan placement + 3D models + screen (both boards)
    Reflow both boards to the PLACEMENT.md contract instead of a mechanical grid:
    - Shield: radios north each behind its SMA, C5 (SPI master) centre with U.FL, the
    3 nRF24 on the back behind the QFN radios, MCP expander on the spine, PN532/flash/
    IR/iButton in their zones, J1 at the (53.57,106) datum, prog header off the crowded
    east edge. Main: pure-UI front (status LEDs, landscape TFT area, PlayStation D-pad
    SW1 up/SW2 down/SW3 left/SW4 right + SW5 select, J1 datum), all electronics on the
    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
    [SnowOwl-Main.kicad_pcb, SnowOwl-Shield.kicad_pcb]
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2026-08-24 PCB: clear mounting-hole keepouts, pull off-board parts in, fix missing models
    Second verification pass with a new thorough checker (mounting-hole clearance +
    3D-model-FILE-exists, not just referenced):
    - Mounting holes: add an M3 screw-head/standoff keepout to the placement engine so
    no support part lands near a corner hole (was dropping caps like C72 onto them).
    Move the parts that sat on holes: shield U9/U6 reflowed in the NE, prog header J40
    off the bottom-left hole; main S3 nudged clear of the NW hole.
    - Off-board: J40 was hanging 4.5mm off the bottom edge (origin at pin 1) and J51 1.8mm
    off the east edge - both pulled fully inside the outline.
    - Missing 3D model files (referenc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
    [SnowOwl-Main.kicad_pcb, SnowOwl-Shield.kicad_pcb]
2026-08-24 PCB: place the missing RV1106, keep parts in their floorplan zones
    Placement audit pass (every netlist part on the board + each near its zone) found and fixed:
    - U30 (RV1106 SoM, a MAIN IC) was NOT on the board: it's the only part with an empty
    footprint field in the netlist, so the importer silently skipped it. Added it with the
    on-disk RV1106_Core1106 placeholder footprint, assigned its 14 nets, placed it in the
    RV1106 zone on the back with J50/J51 nudged clear of it.
    - 4 RV1106 decoupling parts (C94/C95/R95/R96) had wandered ~40mm to the GPS/radio band.
    Two causes: (a) U30's absence left them no zone anchor; (b) they share the CC12_DCPL
    net (see below) which spans the board. Fix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
    [SnowOwl-Main.kicad_pcb, SnowOwl-Shield.kicad_pcb]
2026-08-24 PCB: orient microSD slots to the board edge, USB-C to the bottom-middle edge
    Per the mechanical intent:
    - microSD (J30 main, J51 shield): rotate to rot270 so the CARD SLOT opening faces the
    outside EAST edge - a card now slots straight in from the board edge instead of the slot
    pointing inward. Positioned so the opening sits at the edge.
    - J50 (shield RV1106 USB-C): moved to the bottom-middle on the board edge with the opening
    facing SOUTH, matching J20 on the main board, so it's the charge + power/data port.
    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
    [SnowOwl-Main.kicad_pcb, SnowOwl-Shield.kicad_pcb]
2026-08-24 Schematic: fix the GND<->CC12_DCPL short (empty ground net) + re-import nets
    Root cause of GND having ZERO nodes: in the sub-GHz sheet, C82(+3V3/GND) & C83(CC12_DCPL/GND)
    and C86(+3V3/GND) & C87(SX1262_VREG/GND) were each stacked exactly 12mm apart in the same
    column. connect()'s 5.08mm wire stubs from the upper cap's GND pin snapped onto the lower
    cap's non-GND pin, shorting GND to CC12_DCPL and to SX1262_VREG - which merged every ground
    on the board into CC12_DCPL. Moved C83 and C87 off-column to clear positions.
    - Verified by KiCad's netlister: GND now 64 comps (shield) / 25 (main), was 0; CC12_DCPL
    back to 2 nodes, SX1262_VREG back to 2.
    - Regenerated all sheets, re-exported both netl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
    [SnowOwl-Main.kicad_pcb, SnowOwl-Shield.kicad_pcb, display_ui.kicad_sch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]
2026-08-24 Schematic: set U30 (RV1106) footprint (generator wrote it empty for the custom SnowOwl symbol)
    [rv1106.kicad_sch]
2026-08-24 Schematic: add battery + USB-C charger power subsystem (BQ25896, 2500mAh)
    Adds the full power section to the shield's power sheet, per the battery/stacking research:
    - USB-C (J50 VBUS) -> BQ25896 (3A switch-mode charger + power-path + I2C). Charges a 2500mAh
    1S LiPo (BT50, JST-PH) through DW01A/FS8205 protection (U56); MAX17048 fuel gauge (U57).
    - Power-path SYS -> TPS63020 buck-boost = system +3V3 (holds regulation as the cell sags),
    and -> TPS61230A boost = system +5V (feeds the RV1106). AP7361C LDO still makes clean C5_VDD.
    - Rewired: J50 is now the charge/data input (VBUS), and the RV1106 is powered from the system
    +5V rail instead of being self-powered. +5V/+3V3 distribute to both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
    [display_ui.kicad_sch, esp32c5.kicad_sch, esp32s3.kicad_sch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]
2026-08-24 PCB: place the battery + charger power parts on the shield (south back)
    Import and place the 24 new power components on the shield's south-back, below the RV1106
    and beside the J50 USB-C charge port: BQ25896 charger (U55), TPS63020 buck-boost (U58),
    TPS61230A boost (U59), MAX17048 gauge (U57), DW01 protection (U56), AP7361C LDO (U41),
    three inductors (L55/58/59), the JST battery connector (BT50), and their passives.
    Upgraded the placement anchoring to a SAME-SHEET rule (a support part only anchors to a spec
    IC on its own schematic sheet) instead of the single-point distance heuristic - this keeps
    each part in its floorplan zone and handles the multi-IC power sheet correctly.
    Shield re-veri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
    [SnowOwl-Main.kicad_pcb, SnowOwl-Shield.kicad_pcb]
2026-08-24 Boards: black solder-mask stackup, GND/3V3 plane pours, ESP32-BlackRaven silkscreen art
    - Add a 4-layer stackup with BLACK solder mask to both boards (renders/fab in black).
    - Pour the inner reference planes: solid GND on the 'GND' layer and +3V3 on the '3V3' layer,
    both boards (~6500mm2 / ~5500mm2 coverage).
    - ESP32-BlackRaven branding on the MAIN front: convert the skeletal-raven line-art and the
    bone-font logo to white F.SilkS polygons (scratchpad/img2silk.py, greedy rectangle decomposition
    since bitmap2component is GUI-only) - raven fills the board (~58x81mm, 2419 polys), logo across
    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
    [SnowOwl-Main.kicad_pcb, SnowOwl-Shield.kicad_pcb, display_ui.kicad_sch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]
2026-08-24 Single USB-C + battery power; J1 vertical on the left edge; U30 model; back-side comments
    Power/architecture:
    - Remove J50 (the RV1106's own USB-C). The device now has ONE USB-C: the main board's J20.
    J20's VBUS is carried over J1 pin19 (was SPARE) to the shield's BQ25896 charger, so charging +
    the ESP32-S3 data/programming share the single port. Everything runs off the battery.
    - Reconcile the nets: J20 VBUS -> VBUS (was VBUS_MAIN), charger VBUS <- J1 pin19, RV1106 keeps its
    microSD (J51) but loses its USB port (reached over UART on J1). Removed orphans R95/R96 (J50 CC
    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
    [SnowOwl-Main.kicad_pcb, SnowOwl-Shield.kicad_pcb, display_ui.kicad_sch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]
2026-08-28 Wipe all PCB CAD and start over; keep only the component/schematic research
    The hardware direction is changing, so the whole board design is being restarted from
    scratch rather than carried forward.
    Removed:
    - PCB/v2-compact/ - the full 2-board design (boards, schematics + sub-sheets, custom
    symbols/footprints/3D models, silkscreen artwork, placement).
    - PCB/Assisted/ - the in-progress collaborative re-placement of the shield.
    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
    [SnowOwl-Main.kicad_pcb, SnowOwl-Main.kicad_sch, SnowOwl-Shield.kicad_pcb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]
2026-08-29 S3-Cell: new stackable cellular / counter-surveillance scanner boards
    Base (91x36 mm, 4-layer black solder mask):
    - USB-C receptacle + USBLC6 ESD + 5.1k CC, on the west neck
    - TP4056 charge path + AP2112 3V3 LDO, VBAT/3V3 rails
    - ESP32-S3-WROOM-1U controller with back-side decoupling, BOOT/RESET
    - BG95-M3 LTE-M/NB-IoT + GNSS modem (rot270: ANT east, VBAT/UART/SIM
    south, control north), VBAT bulk, back-side nano-SIM at the south edge
    - Dual edge-mount SMA: cellular (ANT_MAIN) and GPS (ANT_GNSS)
    - TXB0104 1.8<->3.3 V UART level shifter on the back at the modem corner
    Both boards share an identical outline, mounting holes and a DF40C 2x10
    (0.4 mm) board-to-board stack connector. Shield outli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
    [S3-Cell-Base.kicad_pcb, S3-Cell-Shield.kicad_pcb]
2026-08-30 Shield: populate with ESP32-C5 WiFi brain, 0.96" OLED, 3V3 LDO rail
    - ESP32-C5-WROOM-1 (2.4/5 GHz Wi-Fi + BLE), PCB antenna facing the top
    edge (sideways, away from the west USB-C plug and the east cell/GPS SMAs)
    - 0.96" I2C OLED (128x64, SSD1306) at the west for the UI
    - Dedicated AP2112 3V3 LDO rail off VBAT with input/output bulk + module
    decoupling, EN/BOOT strapping
    - I2C pull-ups for the display
    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
    [S3-Cell-Shield.kicad_pcb]
2026-08-30 Shield UI: 1.14" colour TFT + 5-button D-pad; relocate a mounting hole
    - Swap the 0.96" OLED for a 1.14" ST7789 colour IPS TFT (SPI) - represented
    by its 12-pin 0.5mm FPC connector plus a glass outline; drop the I2C
    pull-ups (no longer needed)
    - Add a D-pad next to the screen: up / down / left / right + centre Select
    (B3U-1000P low-profile tacts), matching the reference layout
    - Shift the ESP32-C5 module to the east end (antenna still north) to make
    room for the bigger screen and the buttons
    - Move the second mounting hole off the packed east end (it landed 1.2 mm
    from the GNSS SMA and over the back-side SIM) to centre-north by the stack
    connector; both boards keep identical, ali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
    [S3-Cell-Base.kicad_pcb, S3-Cell-Shield.kicad_pcb]

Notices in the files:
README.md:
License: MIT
